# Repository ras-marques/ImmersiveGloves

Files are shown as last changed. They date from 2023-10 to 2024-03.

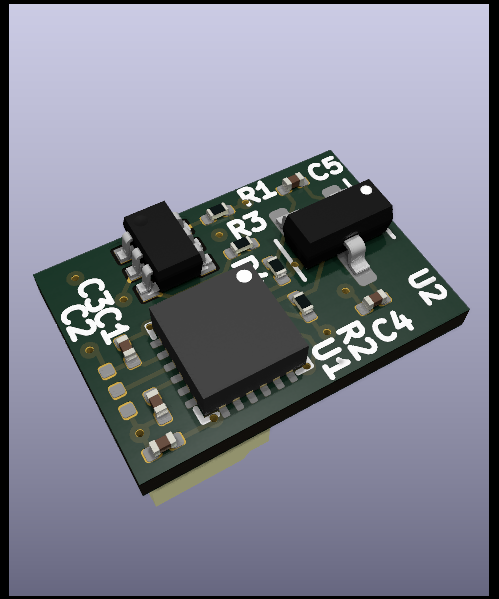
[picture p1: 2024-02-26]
CustomPCBs/InDevelopment/ICM-20948_First_Bone/ICM-20948_First_Bone_top.png

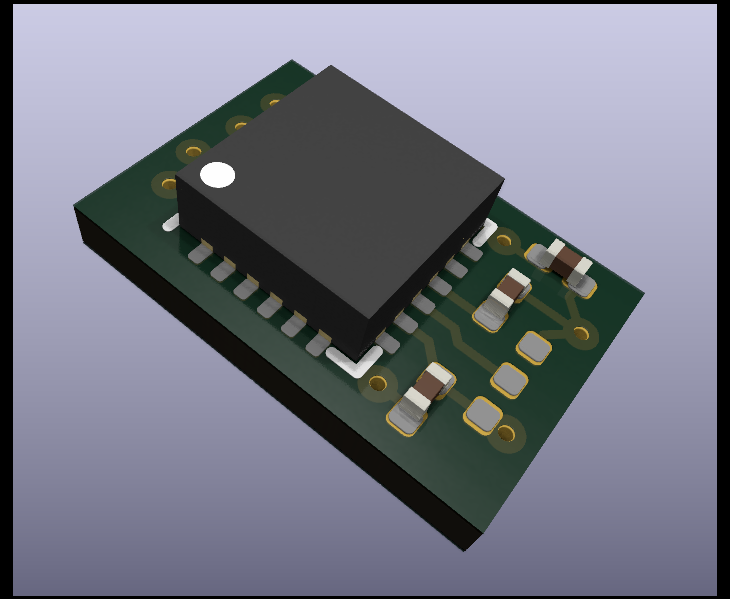
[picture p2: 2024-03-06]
CustomPCBs/InDevelopment/ICM-20948_I2C_1V8_levels/ICM-20948_I2C_1V8_levels_3D_top.png

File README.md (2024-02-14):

# ImmersiveGloves

I want to share how I am making vr gloves using 2 Tundra Trackers, 2 interface boards and 12 inertial sensors.

https://github.com/ras-marques/ImmersiveGloves/assets/6479742/4af1af61-4261-44ce-aa3d-e45de0df7709

Check the full presentation on youtube https://www.youtube.com/watch?v=5OSYiYDkOE8

Hand tracking works with curl and splay on all fingers with 1 IMU on each finger. There is a joystick that is enabled by touching the thumb to the index finger and B, A and System buttons are available by touching the thumb to the middle, ring and pinky fingers respectively.

## Overall repository state

Instructions are incomplete.
The files for the main board and IMU boards are updated.
There is only code for the right glove.
3D printing files need tweaking.

## Necessary equipment and skills

 - Bare PCBs: https://github.com/ras-marques/ImmersiveGloves/tree/main/CustomPCBs/ReadyToTest
 - Components for populating the PCBs: https://github.com/ras-marques/ImmersiveGloves/blob/main/CustomPCBs/cost_analysis.ods
 - Solder paste
 - Hot air gun or hot plate
 - Soldering iron
 - Hot glue gun or super glue
 - 3d printer
 - Pre-crimped JST 1.0mm silicon wire kit: https://www.amazon.es/gp/product/B07PDQKHJ2/ref=ppx_yo_dt_b_asin_title_o00_s00?ie=UTF8&psc=1

The hardest part in this project is making the boards. I am currently not supplying boards, so you will need to order them from somewhere.

The boards are 4 layer and have fine pitch components. Making the PCBs at home is out of the question, but you can order them from JLCPCB, PCBWAY, etc.

I assembled the components on my glove by hand using a stencil to dispense solder paste and used a hot air gun for reflowing. A hot plate is better.

If you don't have a 3d printer, you could order the models from somewhere or ask a friend.

Currently everything is glued to the glove fabric, you could use hot glue or super glue.

The pre-crimped JST wires are necessary to make the assembly process easier, more below.

## Cost analysis

A realistic ballpark for cost is around 250€ per pair of gloves with component and shipping cost and assuming you already have all the tools like a 3d printer, and soldering tools.

You can refer to https://github.com/ras-marques/ImmersiveGloves/blob/main/CustomPCBs/cost_analysis.ods for the complete BOM, but in summary the current cost is described below:
- 4€/pair times 50 = 200€: Cost to make enough boards for exactly 50 pairs of these gloves
- 170€/pair: Cost to source enough components and some spares for a pair of these gloves
- 130€/pair times 50 = 6500€: Cost to source enough compoents for 50 pairs of these gloves

## Tracking method

Why base these gloves around the Tundra Tracker? Using a Tundra Tracker and an expansion board avoids having to deal with batteries, since the Tundra Tracker can power everything. Also, the tracker takes care of transmiting the data from the gloves to the computer wirelessly. Two RP2040's take care of acquiring the data from the 6 inertial sensors, processing it and delivering it to the tracker.

This project is for people that already have a laser tracked VR setup with base stations and ideally for people using Tundra Trackers for full body tracking. That said, if you don't have the Tundra Trackers yet, there are some options:
- 400€: 2 bundles of individual tundra tracker and SW1 dongle (2 USB ports needed) https://unboundxr.eu/tundra-tracker?sqr=tundra + https://unboundxr.eu/tundra-sw1-dongle
- 459€: 3 Tundra Tracker bundle (1 USB port needed) https://unboundxr.eu/tundra-x3-bundle
- 609€: 4 Tundra Tracker bundle (1 USB port needed) https://unboundxr.eu/tundra-x4-bundel

On top of this, if you don't have base stations, those go for 159€ from valve and it is better to have 2.

## End goal for these gloves

- The Tundra Tracker is amazing, it's the smaller tracker available and it even supports sending sensor data to the computer. This is the ultimate tracker for these gloves, but I want to make these more accessible for everyone, so I will want to support more tracking methods, begining with using your available controllers just like LucidVR does. This will probably imply a redesign of the main board to make it possible to power it using an external battery.
- I started this project with the Slime VR BNO085 boards and have since designed a custom BNO085 that is as small as I could make it. I didn't even include a JST connector and wires are soldered directly to it. To make it easier to assemble though, I am considering including the connector in my next IMU boards. I also want to explore using a cheaper IMU chip like the BMI270 with and without a magnetometer.
- My gloves have finger mobility and a low profile as top priorities, so I have no plans for implementing physical buttons unless absolutelly necessary nor force feedback, but vibration haptics are possible if small enough. I do encourage you to do so and share your own version of these gloves!

## Steps to make the gloves:

### 3D Print the mount points for the tracker
- There are 3D printing files available in the 3DPrintingFiles folder of this repo. This is not a one size fits all kind of mount point. I measured the curvature of the back of my hand with a 3D printed matrix of screw inserts, so it fits me perfectly. I will show my process in the future so you can do the same if you want.

### Prepare the Tundra Tracker
- Download the files from this repository.
- Open folder {Steam}\steamapps\common\SteamVR\tools\lighthouse\bin\win32 ({Steam} is probably C:\Program Files (x86)\Steam on your system, but who knows).
- Copy "ImmersiveGlovesLeft.json" and "ImmersiveGlovesRight.json" from this repository into this folder.
- Disconnect every vr device you have from your computer, including the dongles that receive data from the trackers. Using a USB cable, connect just one Tundra Tracker to your computer.
- Write "cmd" on the address bar to open a Command Line inside {Steam}\steamapps\common\SteamVR\tools\lighthouse\bin\win32.
- Write "lighthouse_console.exe" on the Command Line and press return.
- You should see only one device connected, if there are more, make sure to disconnect them, this is **important**. Write "downloadconfig backup.json" to store a backup of the Tundra Tracker config file that is stored inside the tracker.
- Store the config of "ImmersiveGlovesRight.json" to the tracker with "uploadconfig ImmersiveGlovesRight.json" from the command line. This will be the tracker for your right glove.
- Disconnect the tracker and connect another one.
- Store the config of "ImmersiveGlovesLeft.json" to the tracker with "uploadconfig ImmersiveGlovesLeft.json" from the command line. This will be the tracker for your left glove.
- Finally install the ImmersiveGloves driver by copying the folder driverProject/immersive_gloves_controller/build/immersive_gloves_controller on the repository to {Steam}\steamapps\common\SteamVR\drivers\

### Flash the RP2040 board (files not yet available!)
- Download the latest stable version of circuitpython version from here https://circuitpython.org/board/raspberry_pi_pico/
- Connect your expansion board to the Tundra Tracker and then to your PC using the included USB board connected to USB1.
- With the Tracker OFF, press the button on the USB board and while it is pressed, power up the Tundra Tracker, this will let you put the RP2040 in the expansion board in bootloader mode.
- A window should appear on your PC showing the new drive that is emulated by the RP2040. Copy the circuitpython file you downloaded earlier into this folder. The RP2040 will reboot automatically.
- Like before, a new window should appear on your PC showing another drive but now with a different structure. This is where you will put your program that processes the sensor data and sends it to the computer. Just copy the contents of the rp2040Firmware/usb1 folder into the root of this new folder that appeared.
- Repeat the steps above for the second RP2040 mcu by using USB2 and the files in rp2040Firmware/usb2

### Drivers
- We are using the OpenGloves driver so we can easily get inputs working with all apps that support the Index Controllers, which are most of them. So download it from steam: https://store.steampowered.com/app/1574050/OpenGloves/
- Copy the contents of driverProject/immersive_gloves_controller/build/immersive_gloves_controller in this repo to C:\Program Files (x86)\Steam\steamapps\common\SteamVR\drivers or wherever you have your SteamVR app installed.
- Be sure to enable both opengloves and immersive_gloves_controller addon by going to SteamVR settings, Startup/Shutdown tab and clicking Manage SteamVR Add-Ons. These two should be toggled on. Everytime SteamVR shuts down due to an error, it is likely one or both will be toggled off, so check this if something is not working.
- You should calibrate the rotation and position offsets on the OpenGloves configuration panel. I did that manually since I don't have buttons on the glove yet to trigger the callibration interface. Pre-calibrated files may be available in the future with instructions on how to use them.

## Important resources that made this project possible
 
Tundra Labs have a repo with some documentation on how to use their development board https://github.com/tundra-labs/rp2040_examples

CircuitPython allowed me to easily get the inertial sensors working without me having to program everything from scratch, you can learn more about this here https://learn.adafruit.com/adafruit-9-dof-orientation-imu-fusion-breakout-bno085/python-circuitpython

Finally Functional's Open VR Driver Tutorial that was a great introduction on how OpenVR inputs work https://www.youtube.com/watch?v=LzEIOBnbC8k

OpenVR repository has lots of documentation, it takes a while to figure out the parts that are important for this project, but it's worth the effort https://github.com/ValveSoftware/openvr

[danwillm](https://github.com/danwillm) helped me get this thing started by pointing me in the right direction, telling me what technologies to use to speak with the tracker and openvr.

## Contributing workflow

Here’s how I suggest you go about proposing a change to this project:

1. [Fork this project][fork] to your account.
2. [Create a branch][branch] for the change you intend to make.
3. Make your changes to your fork.
4. [Send a pull request][pr] from your fork’s branch to our `main` branch.

Using the web-based interface to make changes is fine too, and will help you by automatically forking the project and prompting to send a pull request too.

[fork]: https://help.github.com/articles/fork-a-repo/
[branch]: https://help.github.com/articles/creating-and-deleting-branches-within-your-repository
[pr]: https://help.github.com/articles/using-pull-requests/

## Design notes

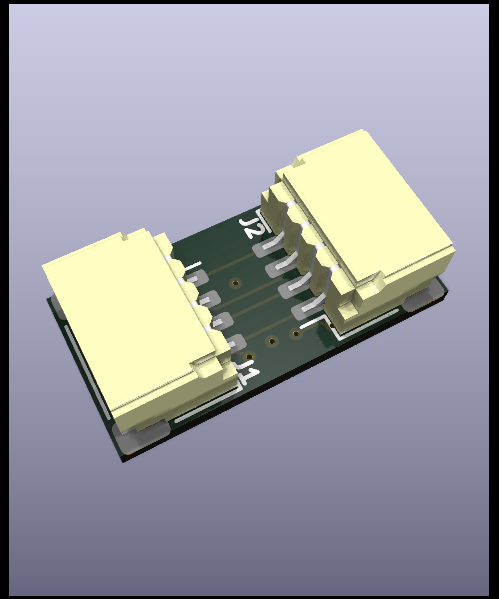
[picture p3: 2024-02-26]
CustomPCBs/InDevelopment/BMI160-and-QMC5883L_Second_Bone/BMI160-and-QMC5883L_Second_Bone_bot.png

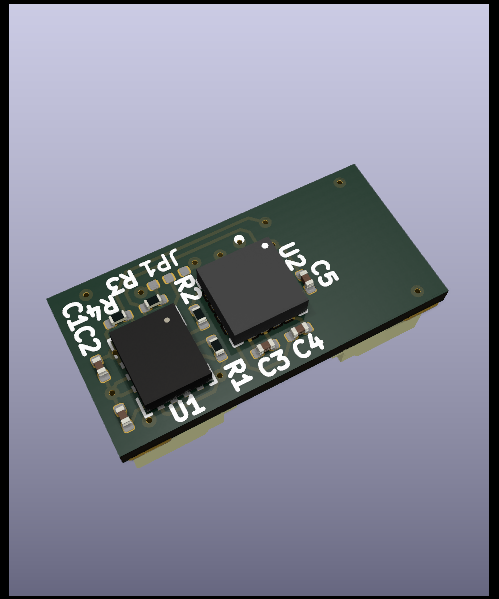
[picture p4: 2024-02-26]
CustomPCBs/InDevelopment/BMI160-and-QMC5883L_Second_Bone/BMI160-and-QMC5883L_Second_Bone_top.png

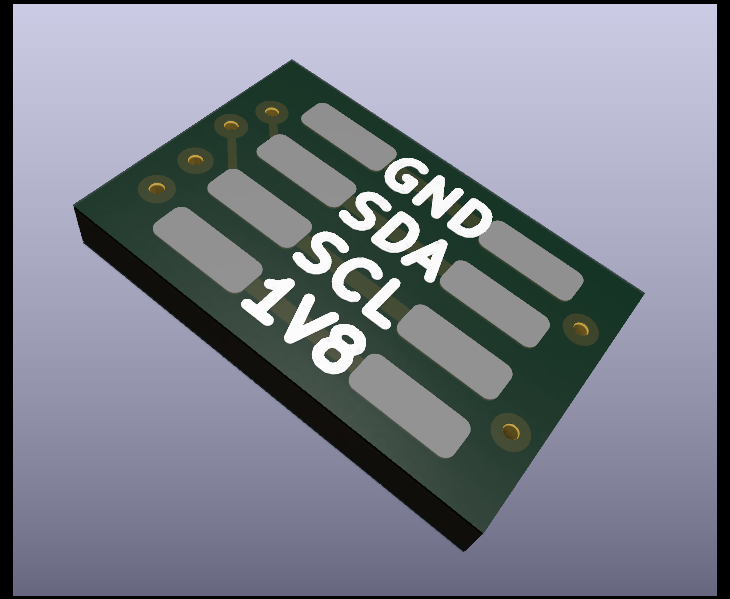
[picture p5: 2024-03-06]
CustomPCBs/InDevelopment/ICM-20948_I2C_1V8_levels/ICM-20948_I2C_1V8_levels_3D_bot.png

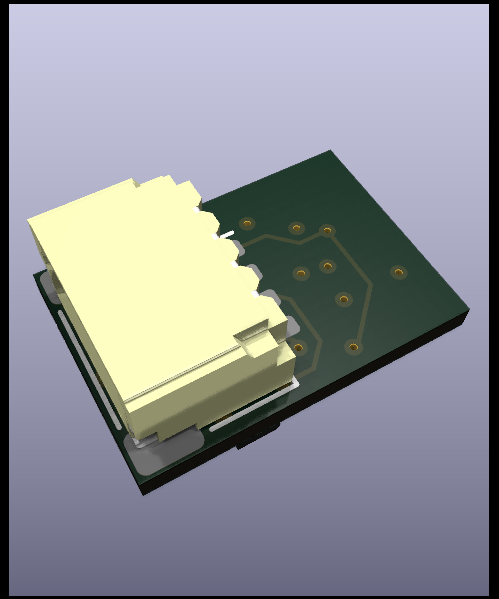
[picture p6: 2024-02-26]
CustomPCBs/InDevelopment/ICM-20948_First_Bone/ICM-20948_First_Bone_bot.png

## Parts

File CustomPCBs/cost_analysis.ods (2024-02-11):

# | Reference | Qty | Value | Footprint | DNP | total/pair | total combined/pair | max unit price | max price/pair | store item | total/50 pairs | min unit price | min price/50 pairs | store item
Expansion Boards |  |  |  |  |  |  |  | minimum qty |  |  |  | enough qty
1 | C1, C7, C10, C17, C23, C28 | 6 | 2.2u | Capacitor_SMD:C_0402_1005Metric |  | 12 | 12 | 0.014 | 0.168 | https://pt.farnell.com/samsung-electro-mechanics/cl05a225mq5nnnc/cap-2-2uf-6-3v-mlcc-0402/dp/3013335 | 600 | 0.007 | 4.2 | https://pt.farnell.com/samsung-electro-mechanics/cl05a225mq5nnnc/cap-2-2uf-6-3v-mlcc-0402/dp/3013335
2 | C2, C3, C4, C5, C6, C8, C9, C13, C14, C18, C20, C22, C24, C25, C26, C27 | 16 | 100n | Capacitor_SMD:C_0402_1005Metric |  | 32 | 62 | 0.004 | 0.248 | https://pt.farnell.com/multicomp/mc0402x104m160ct/cap-0-1-f-16v-20-x5r-0402/dp/2627420 | 3100 | 0.004 | 12.4 | https://pt.farnell.com/multicomp/mc0402x104m160ct/cap-0-1-f-16v-20-x5r-0402/dp/2627420
3 | C11, C12, C19, C21 | 4 | 27p | Capacitor_SMD:C_0402_1005Metric |  | 8 | 8 | 0.008 | 0.064 | https://pt.farnell.com/kemet/c0402c270k5gactu/cap-27pf-50v-10-c0g-np0-0402/dp/2904560 | 400 | 0.008 | 3.2 | https://pt.farnell.com/kemet/c0402c270k5gactu/cap-27pf-50v-10-c0g-np0-0402/dp/2904560
4 | C15, C16 | 2 | 22p | Capacitor_SMD:C_0402_1005Metric |  | 4 | 24 | 0.011 | 0.264 | https://pt.farnell.com/multicomp/mc0402n220j250ct/cap-22pf-25v-5-c0g-np0-0402/dp/2627394 | 1200 | 0.004 | 4.8 | https://pt.farnell.com/multicomp/mc0402n220j250ct/cap-22pf-25v-5-c0g-np0-0402/dp/2627394
5 | FINGER1, FINGER2, FINGER3, FINGER4, FINGER5L1, FINGER5R1, USB1, USB2 | 8 | Conn_01x04 | Connector_JST:JST_SH_SM04B-SRSS-TB_1x04-1MP_P1.00mm_Horizontal |  | 16 | 16 | 0.327 | 5.232 | https://pt.farnell.com/jst-japan-solderless-terminals/sm04b-srss-tb-lf-sn/connector-header-smt-r-a-1mm-4way/dp/1830839 | 800 | 0.226 | 180.8 | https://pt.farnell.com/jst-japan-solderless-terminals/sm04b-srss-tb-lf-sn/connector-header-smt-r-a-1mm-4way/dp/1830839
6 | FingerAux1 | 1 | Conn_01x08 | Connector_JST:JST_SH_SM08B-SRSS-TB_1x08-1MP_P1.00mm_Horizontal |  | 2 | 2 | 0.784 | 1.568 | https://pt.farnell.com/jst-japan-solderless-terminals/sm08b-srss-tb-lf-sn/header-r-a-8way/dp/1679124 | 100 | 0.648 | 64.8 | https://pt.farnell.com/jst-japan-solderless-terminals/sm08b-srss-tb-lf-sn/header-r-a-8way/dp/1679124
7 | J1 | 1 | Conn_01x25 | my_connectors:25PIN FRONT FLIP 0.6mm PITCH AYF332535A |  | 2 | 2 | 1.75 | 3.5 | https://pt.mouser.com/ProductDetail/Panasonic-Industrial-Devices/AYF332535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 | 100 | 1.37 | 137 | https://pt.mouser.com/ProductDetail/Panasonic-Industrial-Devices/AYF332535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
8 | R1, R8 | 2 | 200 | Resistor_SMD:R_0402_1005Metric |  | 4 | 4 | 0.004 | 0.016 | https://pt.farnell.com/en-PT/multicomp/mcwr04x2000ftl/res-200r-1-0-0625w-thick-film/dp/2447132 | 200 | 0.0033 | 0.66 | https://pt.farnell.com/en-PT/multicomp/mcwr04x2000ftl/res-200r-1-0-0625w-thick-film/dp/2447132
9 | R2, R7, R9, R10 | 4 | 1k | Resistor_SMD:R_0402_1005Metric |  | 8 | 8 | 0.005 | 0.04 | https://pt.farnell.com/en-PT/multicomp/mcwr04x1001ftl/res-1k-1-0-0625w-thick-film/dp/2447120 | 400 | 0.002 | 0.8 | https://pt.farnell.com/en-PT/multicomp/mcwr04x1001ftl/res-1k-1-0-0625w-thick-film/dp/2447120
10 | R3, R4 | 2 | 10k | Resistor_SMD:R_0402_1005Metric |  | 4 | 24 | 0.005 | 0.12 | https://pt.farnell.com/en-PT/multicomp/mcmr04x1002ftl/res-10k-1-0-063w-0402-ceramic/dp/2072517 | 1200 | 0.0015 | 1.8 | https://pt.farnell.com/en-PT/multicomp/mcmr04x1002ftl/res-10k-1-0-063w-0402-ceramic/dp/2072517
11 | R5, R6 | 2 | 2k2 | Resistor_SMD:R_0402_1005Metric |  | 4 | 24 | 0.005 | 0.12 | https://pt.farnell.com/multicomp/mcmr04x2201ftl/res-2k2-1-0-0625w-0402-ceramic/dp/2072780 | 1200 | 0.0019 | 2.28 | https://pt.farnell.com/multicomp/mcmr04x2201ftl/res-2k2-1-0-0625w-0402-ceramic/dp/2072780
12 | U1, U5 | 2 | RP2040 | Package_DFN_QFN:QFN-56-1EP_7x7mm_P0.4mm_EP3.2x3.2mm |  | 4 | 4 | 0.755 | 3.02 | https://pt.farnell.com/raspberry-pi/rp2040ct/mcu-32bit-133mhz-qfn-56/dp/3766082?st=rp2040 | 200 | 0.755 | 151 | https://pt.farnell.com/raspberry-pi/rp2040ct/mcu-32bit-133mhz-qfn-56/dp/3766082?st=rp2040
13 | U2, U4 | 2 | W25Q64JVSSIQ | Package_SO:SOP-8_5.28x5.23mm_P1.27mm |  | 4 | 4 | 0.949 | 3.796 | https://pt.mouser.com/ProductDetail/Winbond/W25Q64JVSSIQ?qs=qSfuJ%252Bfl%2Fd4DecxlHDmB8w%3D%3D | 200 | 0.761 | 152.2 | https://pt.mouser.com/ProductDetail/Winbond/W25Q64JVSSIQ?qs=qSfuJ%252Bfl%2Fd4DecxlHDmB8w%3D%3D
14 | U3 | 1 | BNO085 | Package_LGA:LGA-28_5.2x3.8mm_P0.5mm |  | 2 | 12 | 11.76 | 141.12 | https://pt.mouser.com/ProductDetail/CEVA/BNO085?qs=ulEaXIWI0c9BFVeZDQCmmQ%3D%3D | 600 | 8.89 | 5334 | https://pt.mouser.com/ProductDetail/CEVA/BNO085?qs=ulEaXIWI0c9BFVeZDQCmmQ%3D%3D
15 | Y1, Y2 | 2 | 12.000MHz | Crystal:Crystal_SMD_3225-4Pin_3.2x2.5mm |  | 4 | 4 | 0.226 | 0.904 | https://pt.farnell.com/ilsi-america/ilcx13-fb5f18-12-000mhz/crystal-12mhz-18pf-smd-3-2mm-x/dp/3572980 | 200 | 0.189 | 37.8 | https://pt.farnell.com/ilsi-america/ilcx13-fb5f18-12-000mhz/crystal-12mhz-18pf-smd-3-2mm-x/dp/3572980
16 | Y3 | 1 | 32.768kHz | Crystal:Crystal_SMD_2012-2Pin_2.0x1.2mm |  | 2 | 12 | 0.47 | 5.64 | https://pt.farnell.com/en-PT/ecs-inc-international/ecs-327-12-5-12-c/crystal-32-768khz-12-5pf-2mm-x/dp/3649608 | 600 | 0.347 | 208.2 | https://pt.farnell.com/en-PT/ecs-inc-international/ecs-327-12-5-12-c/crystal-32-768khz-12-5pf-2mm-x/dp/3649608
 |  |  |  |  |  |  |  | Total | 165.82 |  |  | Total | 6295.94
IMU Boards |  |  |  |  |  |  |  |  |  |  |  | Total/pair | 125.9188
1 | C1, C2, C6 | 3 | 100n | Capacitor_SMD:C_0402_1005Metric |  | 30 |  |  |  |  | 1500
2 | C4, C5 | 2 | 22p | Capacitor_SMD:C_0402_1005Metric |  | 20 |  |  |  |  | 1000
3 | J1 | 1 | Conn_01x04_Pin | Library:WireToBoard2x2Wide |  | 10 |  |  |  |  | 500
4 | R1, R2 | 2 | 2k2 | Resistor_SMD:R_0402_1005Metric |  | 20 |  |  |  |  | 1000
5 | R3, R4 | 2 | 10k | Resistor_SMD:R_0402_1005Metric |  | 20 |  |  |  |  | 1000
6 | U1 | 1 | BNO085 | Package_LGA:LGA-28_5.2x3.8mm_P0.5mm |  | 10 |  |  |  |  | 500
7 | Y1 | 1 | 32.768kHz | Crystal:Crystal_SMD_2012-2Pin_2.0x1.2mm |  | 10 |  |  |  |  | 500

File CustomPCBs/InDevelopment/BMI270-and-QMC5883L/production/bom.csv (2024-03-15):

Designator | Footprint | Quantity | Value | LCSC Part #
C1 | 0603 | 1 | 4.7u | C5252398
C2 | 0201 | 1 | 220n | C962109
C3, C4, C5 | 0201 | 3 | 100n | C2909627
R1, R2 | 0201 | 2 | 2k2 | C142018
U1 | XDCR_BMI270 | 1 | BMI270 | C2836813
U2 | XDCR_HMC5883L-TR | 1 | QMC5883L | C976032

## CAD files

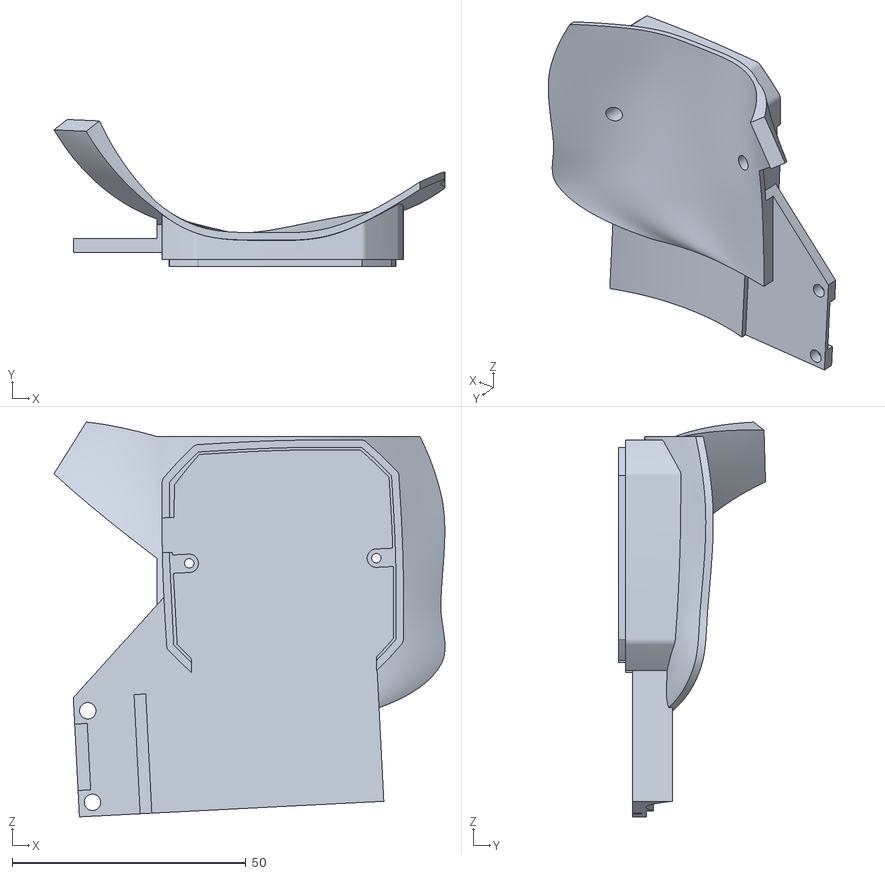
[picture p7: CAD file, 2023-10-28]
3DPrintingFiles/Prototypes/ImmersiveGlovesLeft.stl
83.5 x 31.4 x 84.4

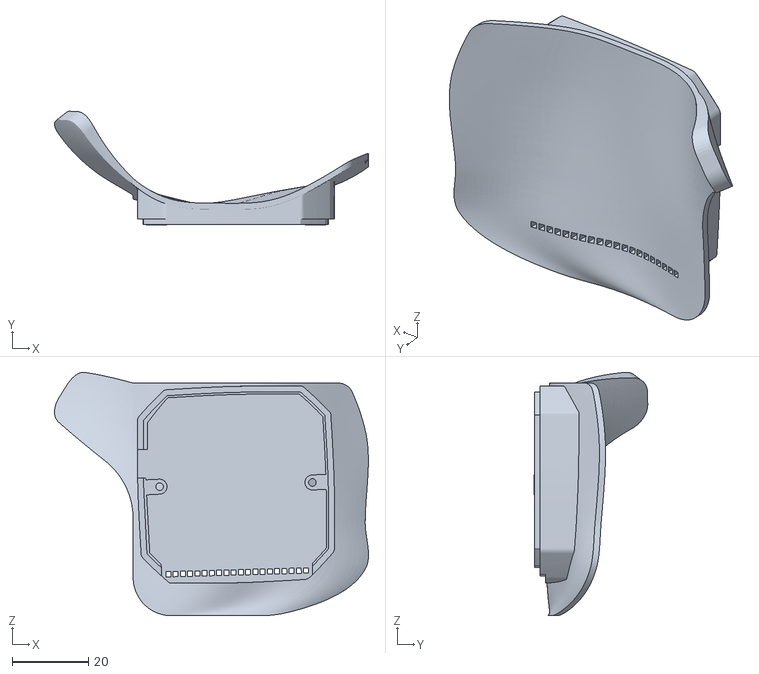
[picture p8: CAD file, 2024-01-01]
3DPrintingFiles/ReadyToTest/BackPlate/BackPlateHolesForWires.stl
82.1 x 29.7 x 63.7

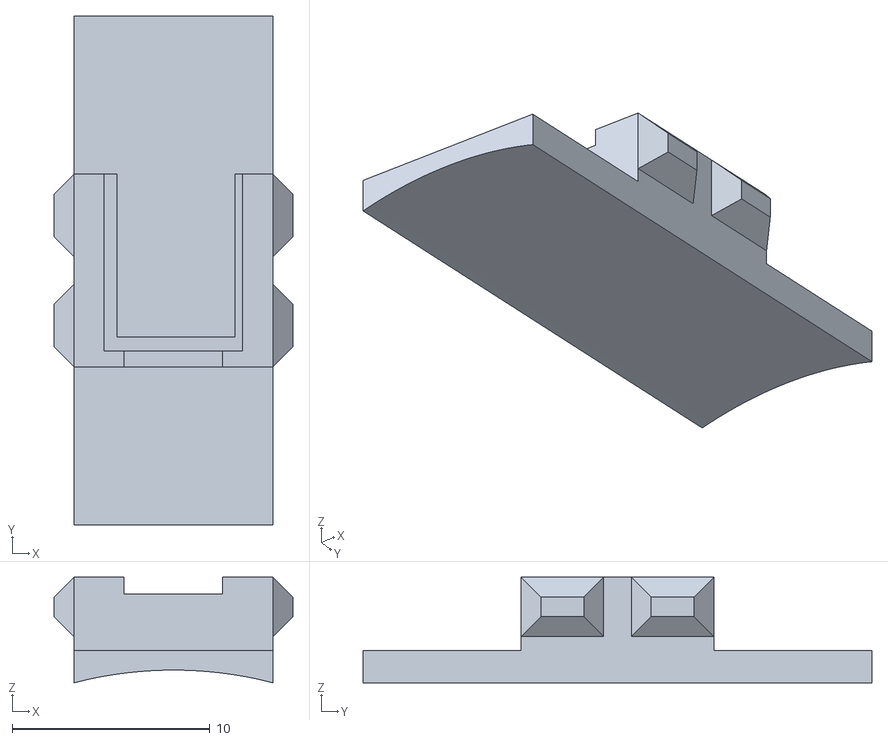
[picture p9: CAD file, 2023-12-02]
3DPrintingFiles/ReadyToTest/IMUHousing/IMUHousingBottomV2.stl
12.1 x 25.8 x 5.34

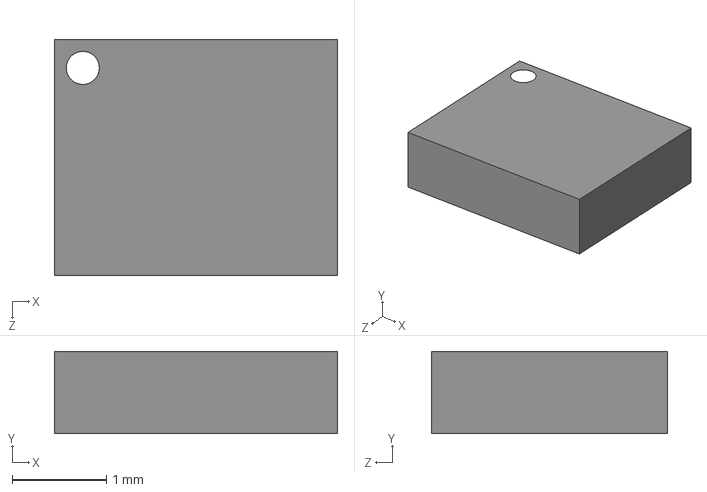
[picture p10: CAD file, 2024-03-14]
CustomPCBs/ComponentLibraries/3dmodels/BMI270.step
3.00 x 0.87 x 2.50 mm

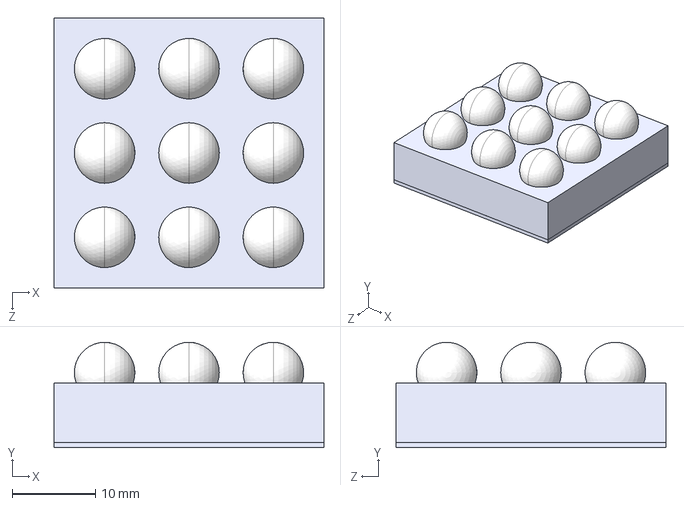
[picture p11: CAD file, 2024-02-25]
CustomPCBs/ComponentLibraries/BMM350.stp
32.5 x 12.7 x 32.5 mm

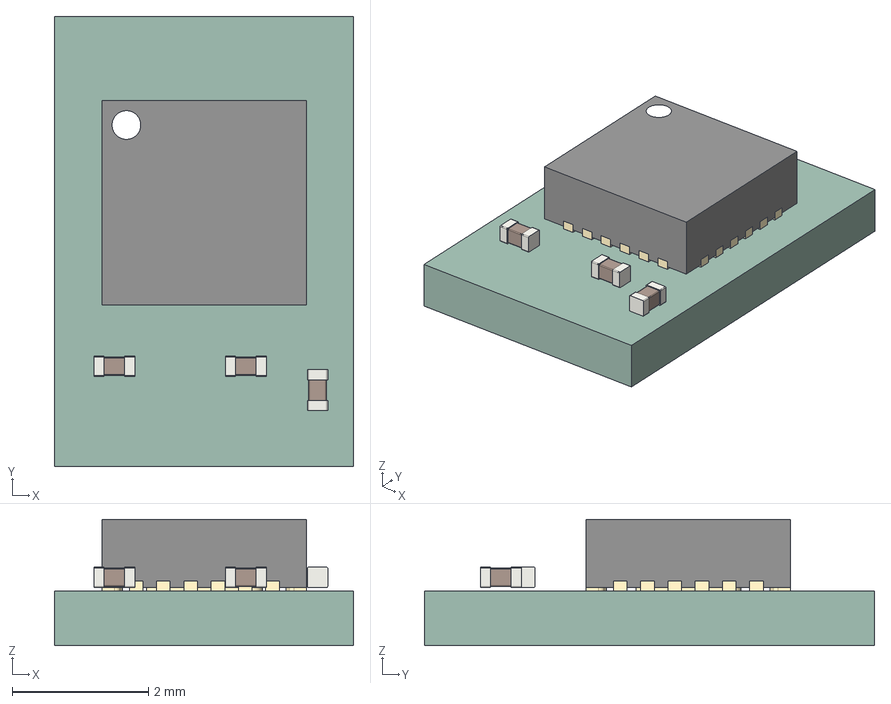
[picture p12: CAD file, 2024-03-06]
CustomPCBs/InDevelopment/ICM-20948_I2C_1V8_levels/ICM-20948_I2C_1V8_levels.step
4.39 x 6.60 x 1.85 mm
ICM-20948_I2C_1V8_levels PCB

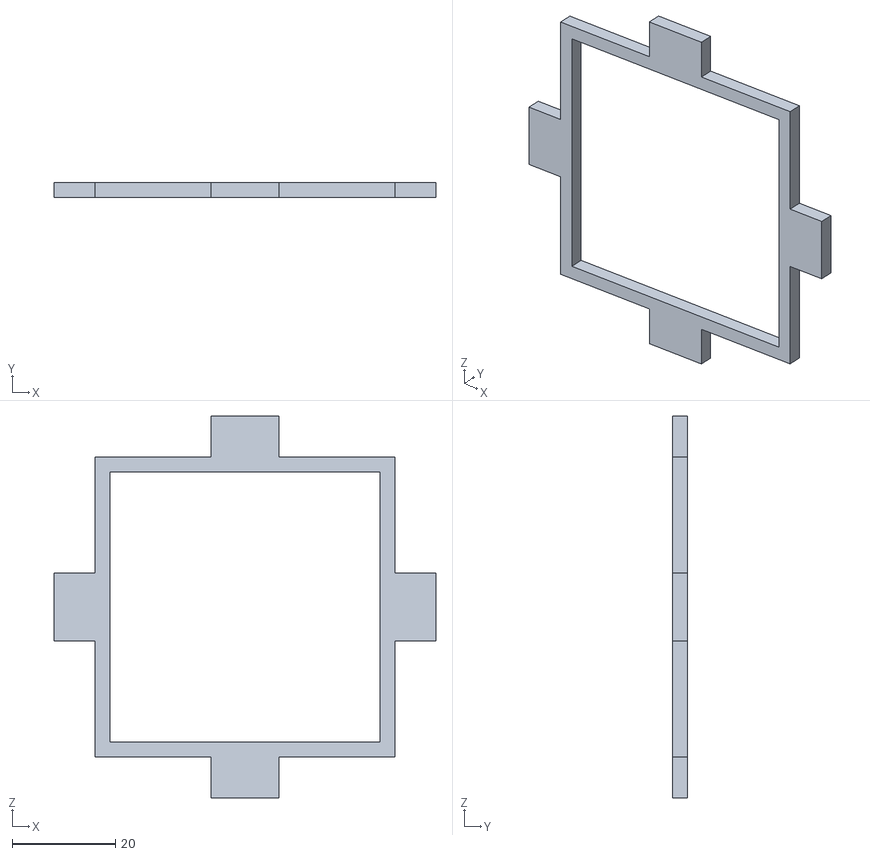
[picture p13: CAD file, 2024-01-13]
CustomPCBs/InDevelopment/tundraIOExpansion/StencilJig/StencilTop.stl
74.1 x 3.00 x 74.1

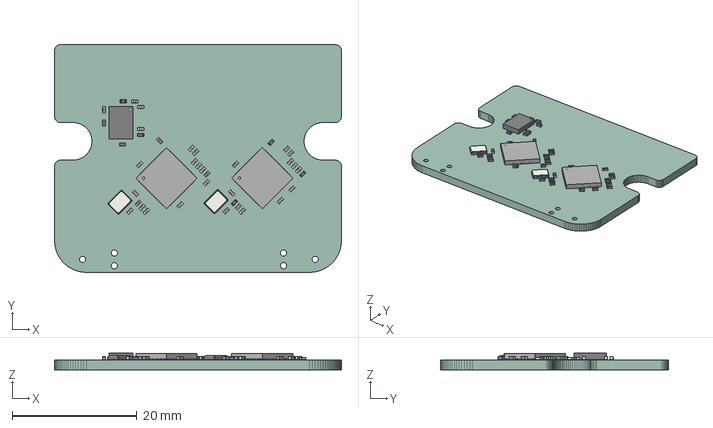
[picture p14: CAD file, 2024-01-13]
CustomPCBs/InDevelopment/tundraIOExpansion/tundraIOExpansion.step
46.0 x 36.5 x 2.67 mm
tundraIOExpansion PCB

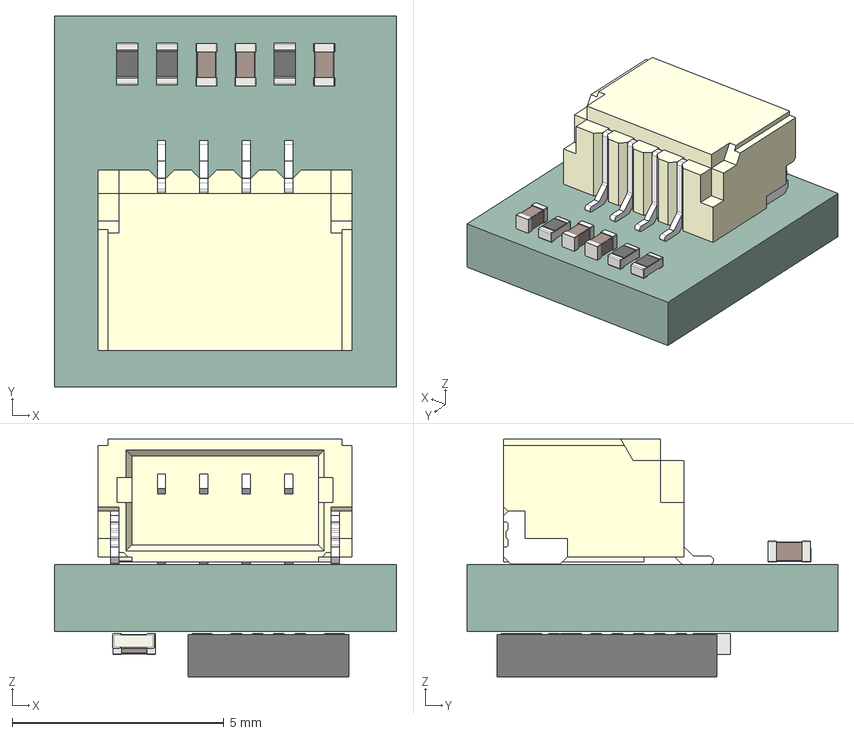
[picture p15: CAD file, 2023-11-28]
CustomPCBs/ReadyToTest/BNO085_0x4B_Board/BNO085_0x4B_Board.step
8.07 x 8.75 x 5.61 mm
BNO085_0x4A_Board PCB

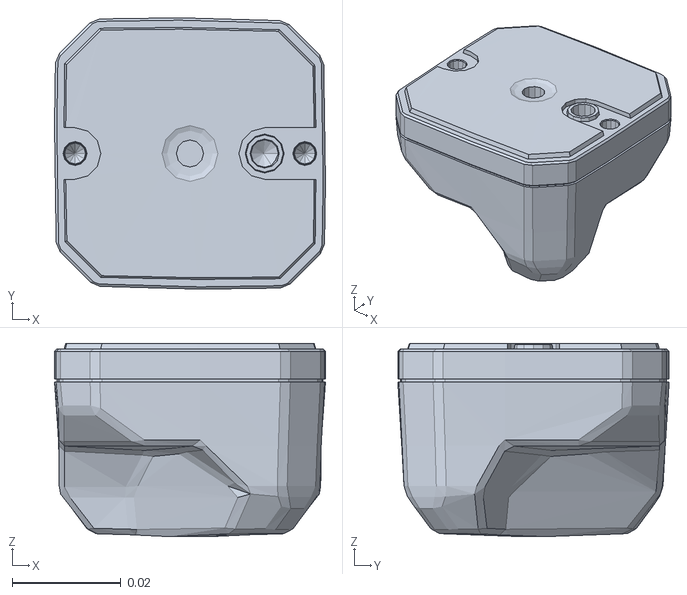
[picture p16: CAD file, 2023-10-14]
driverProject/immersive_gloves_controller/build/immersive_gloves_controller/resources/immersive_gloves_controller/immersive_gloves_controller.obj
0.0499 x 0.05 x 0.0356

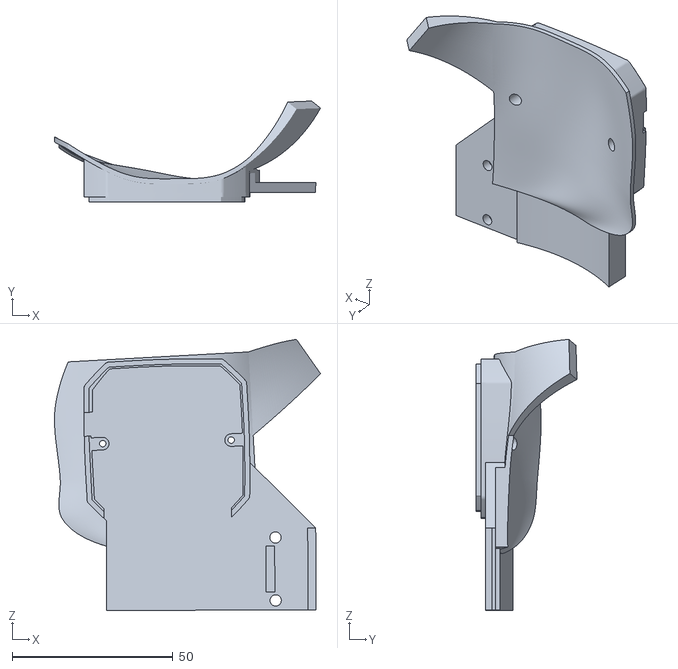
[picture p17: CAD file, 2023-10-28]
3DPrintingFiles/Prototypes/ImmersiveGlovesRight.stl
82.8 x 31.4 x 84.4

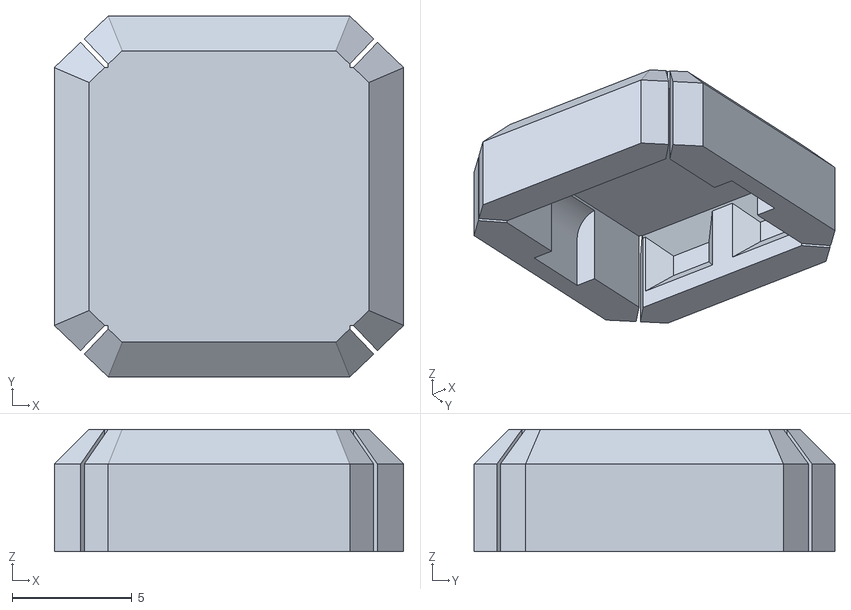
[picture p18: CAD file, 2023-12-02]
3DPrintingFiles/ReadyToTest/BackPlate/IMUHardPointLid.stl
14.6 x 15.0 x 5.11

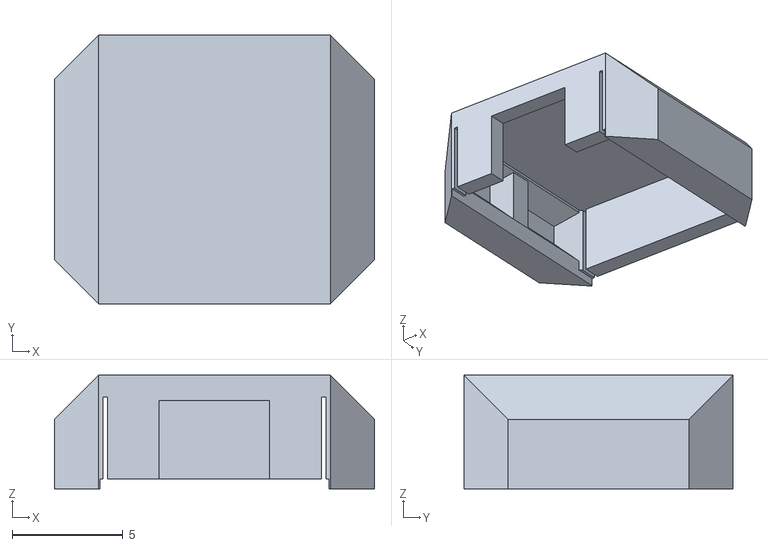
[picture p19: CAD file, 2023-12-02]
3DPrintingFiles/ReadyToTest/IMUHousing/IMUHousingTopV2.stl
14.5 x 12.2 x 5.15

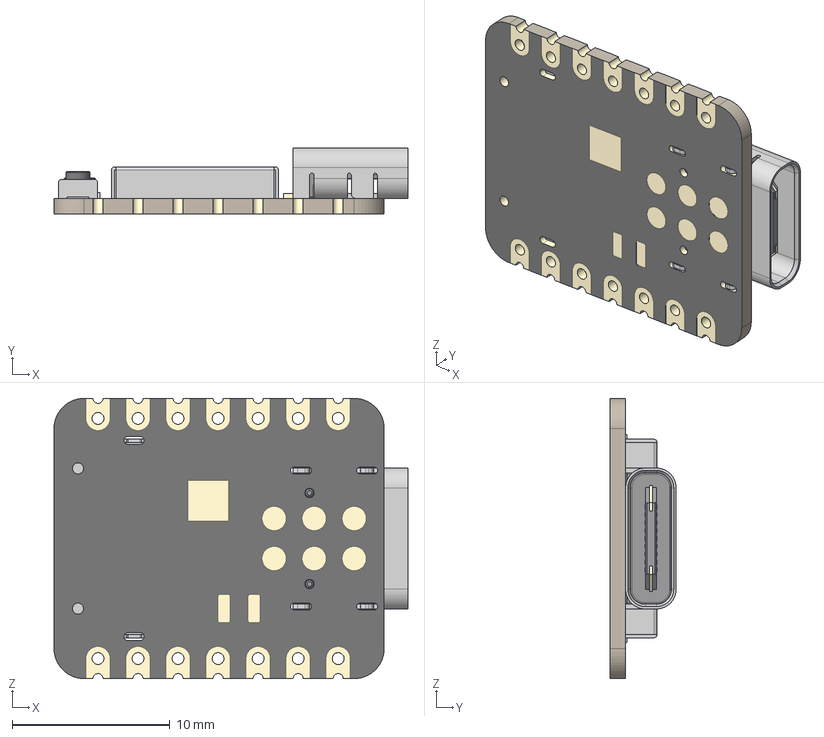
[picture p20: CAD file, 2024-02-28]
CustomPCBs/ComponentLibraries/3dmodels/Seeed Studio XIAO-ESP32-C3.step
22.5 x 4.21 x 17.8 mm
BOSS-EXTRUDE14_8_
BOSS-EXTRUDE7_4_
BOSS-EXTRUDE7_3_
BOSS-EXTRUDE14_4_
BOSS-EXTRUDE14_2_
BOSS-EXTRUDE14_11_
BOSS-EXTRUDE7_7_
BOSS-EXTRUDE14_9_
BOSS-EXTRUDE14_3_
BOSS-EXTRUDE14_7_
MIRROR2
BOSS-EXTRUDE14_5_
BOSS-EXTRUDE14_12_
BOSS-EXTRUDE7_8_
BOSS-EXTRUDE7_1_
BOSS-EXTRUDE14_10_
BOSS-EXTRUDE7_9_
BOSS-EXTRUDE14_6_
BOSS-EXTRUDE14_1_
BOSS-EXTRUDE7_6_
BOSS-EXTRUDE7_2_
CUT-EXTRUDE5
BOSS-EXTRUDE7_5_
U.FL Connector v1
Button (1) x 2
Shield

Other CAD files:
CustomPCBs/ReadyToTest/BNO085_0x4A_Board/StensilJig/StensilJig.FCStd
CustomPCBs/InDevelopment/tundraIOExpansion/StencilJig/StencilBottom.stl
3DPrintingFiles/ReadyToTest/BackPlate/BackPlate.stl
CustomPCBs/ComponentLibraries/3dmodels/6-TSOP.STEP
3DPrintingFiles/ReadyToTest/BackPlate/IMUHardPoint.stl
3DPrintingFiles/ReadyToTest/IMUHousing/IMUHousing.f3d
3DPrintingFiles/ReadyToTest/IMUHousing/IMUHousingBottom.stl
3DPrintingFiles/ReadyToTest/IMUHousing/IMUHousingTop.stl
CustomPCBs/ComponentLibraries/3dmodels/BSS138BKS,115.stp
CustomPCBs/ComponentLibraries/3dmodels/BSS138W-7-F.step
CustomPCBs/ComponentLibraries/3dmodels/HMC5883L-TR.step
CustomPCBs/ComponentLibraries/3dmodels/ICM-20948.step
CustomPCBs/ComponentLibraries/3dmodels/LGA14-L_2P59X3P1X0P5_STM.step
CustomPCBs/ComponentLibraries/3dmodels/SM04B-SRSS-TB.STEP
CustomPCBs/ComponentLibraries/3dmodels/User Library-SOT23-3.step
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

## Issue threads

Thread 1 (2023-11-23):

Add code support for cheaper IMU solutions

ras-marques, 2023-11-23:
We are currently using BNO boards that cost around 15€ each and needing 6 per glove.

There is an existing board we can use to develop the code for the project:
https://oshwlab.com/neosquared2002/MultIMU-Module-for-SlimeVR

I didn't find an off the shelf board that includes a BMI270 and magnetometer, but please share if you know where to get them so development is faster.

ras-marques, 2024-03-07:
https://oshwlab.com/neosquared2002/MultIMU-Module-for-SlimeVR was deleted in the meantime.

SlimeVR already has some code for the next IMU I want to use, the ICM-20948, will focus on porting that next.

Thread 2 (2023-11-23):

Design cheaper IMU board

ras-marques, 2023-11-23:
While not knowing exactly what IMUs to use, the BMI270 together with a magnetometer is a good option. The goal is for the board to fit the fingernail. 4 Layer boards and components on both sides are a must for this to work.

DregonMMM, 2023-11-30:
Both the BMI270 and BMI160 are good options. They are also not too big and use the same pinout so for a custom PCB with a magnetometer you only need a single board design because both chips can be used. If budget is a problem and you don't mind having to recalibrate them more often then you don't need the magnetometer.

ras-marques, 2024-03-07:
ICM-20948 based board has been designed, will close after confirming it is working.

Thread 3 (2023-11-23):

Design hardpoints where to place the IMU boards

ras-marques, 2023-11-23:
The IMU boards need to be fixed to the glove somehow. On the prototype they were hot glued to a 3D printed hardpoint that was also hot glued to the glove.

A better option would be to sew or/and super glue the hardpoint to the glove and clamp the IMU board to it somehow.

We should support people using regular FDM printers but also people with resin printers of greater resolution, hence allowing for smaller hardpoints.

ras-marques, 2023-12-05:
Solved, check [here](https://github.com/ras-marques/ImmersiveGloves/tree/main/3DPrintingFiles)

Closed 2023-12-05.

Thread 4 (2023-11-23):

Find a robust and easy way to route cables from the back of the hand to the finger tips

ras-marques, 2023-11-23:
Our finger sensors are currently on the tip of the fingers. This poses a challenge in routing power and communication from our RP2040 microcontrollers to the IMU boards.

The prototype has hot glue "clips" keeping the cables from going super wild, but a better solution should be used, such as embedding the wires onto the glove fibers, almost like sewing but with copper cables.

ras-marques, 2023-12-05:
The IMU boards were moved to the second finger bone counting from the tip and a hardpoint was designed and prototyped, available [here](https://github.com/ras-marques/ImmersiveGloves/tree/main/3DPrintingFiles). The copper wires are threaded through the glove fabric up to the backplate where the acquisition board is located. This is not an easy task, new wire types should be used, maybe enameled wire is a good option, but special care should be taken during assembly so that the wires don't break over time. More prototyping and testing is needed.

ras-marques, 2024-03-07:
Now using silicone wire, this can be closed.

Closed 2024-03-07.

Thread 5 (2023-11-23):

Design joystick and button interface

ras-marques, 2023-11-23:
My current idea is to coat some parts of the glove with a conductive paste like some sports gloves use to add touchscreen support, and tracking what fingers are in contact with what parts of the glove. Then depending on the motion after contact of the thumb with a part of the glove for example, a kind of input is sent to the computer.

ras-marques, 2023-12-05:
This is now being solved by contacts with a wire mesh on the glove for joystick and buttons, with the joystick being emulated by the attitude of the thumb when it touches a specific area of the glove.

Closed 2023-12-05.

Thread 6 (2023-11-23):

Add more I2C support to the RP2040

ras-marques, 2023-11-23:
We currently need 2 RP2040 to take care of 6 I2C BNO085 boards, since the RP2040 only has 2 I2C interfaces and the BNO085 can only have 2 different addresses, leaving us with each RP2040 being able to support up to 4 IMU boards.

This could be improved in many ways, either by designing the BNO085 boards to use UART or SPI instead of I2C, but I currently don't have that available. I have already tried implementing bitbanged I2C and the data rate plummets from 100Hz to 8Hz, becoming noticeably choppy.

The RP2040 has a super power though, it's PIO machines, that allow us to program mostly any interface in any pin. I haven't tried I2C with PIO, but will be happy if someone manages to get a BNO085 speaking using a PIO emulated I2C device. This would allow for mode space in the main board and more space = more features.

ras-marques, 2024-03-07:
Must try multiplexing I2C on the RP2040 itself, should be possible. What I want to do is reconfigure the same peripheral on other pins between acquisitions. Overhead is probably minimal, but must check.

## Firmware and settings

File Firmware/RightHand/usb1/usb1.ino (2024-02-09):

// #include "tundra_mapped_input.h"
#include "BNO085.h"
#include "Finger.h"
#include "Quaternion.h"
#include <cmath>

#include <hardware/pio.h>

// Our assembled program:
#include "spi_slave.pio.h"

// Any button interaction in the glove is done by touching the thumb to one of the fingers.
// This makes accidental button presses very frequent. To avoid this, a double click on the A button (ring finger) must be executed.
// This action will toggle inputs on and off, while never disabling hand tracking.
bool disableInputs = true;

// Create TMI object to communicate with Tundra Tracker
// TMI tundra_tracker;
// void csn_irq( uint gpio, uint32_t event_mask );  // Chip select IRQ must be top level so let's make one and connect it later in setup

BNO085 bnoIndex;
BNO085 bnoMiddle;
BNO085 bnoRing;
BNO085 bnoPinky;

Finger fingerIndex;
Finger fingerMiddle;
Finger fingerRing;
Finger fingerPinky;

Quaternion handQuaternion;
Quaternion relativeQuaternion;

Quaternion indexQuaternion;
Quaternion middleQuaternion;
Quaternion ringQuaternion;
Quaternion pinkyQuaternion;

float getCurl(Quaternion q){
  return atan2(2 * (q.x * q.w - q.y * q.z), 1 - 2 * (q.x * q.x + q.y * q.y));
}

float getSplay(Quaternion q){
  return atan2(2 * (q.x * q.y + q.z * q.w), 1 - 2 * (q.y * q.y + q.z * q.z));
}

float getRoll(Quaternion q){
  return atan2(2 * (q.y * q.z + q.w * q.x), 1 - 2 * (q.x * q.x + q.y * q.y));
}

// this will be sent by serial to the main MCU - 14 bytes are enough for 112 bits, this struct has 108
typedef struct __attribute__( ( packed, aligned( 1 ) ) )
{
  uint8_t       pinky           : 1;  //0
  uint8_t       ring            : 1;  //1
  uint8_t       middle          : 1;  //2
  uint8_t       index           : 1;  //3
  uint16_t      thumbstick_x    : 10; //4
  uint16_t      thumbstick_y    : 10; //14
  uint16_t      thumbCurl       : 10; //24
  uint16_t      thumbSplay      : 10; //34
  int16_t       refQuaternion_w : 16; //44
  int16_t       refQuaternion_x : 16; //60
  int16_t       refQuaternion_y : 16; //76
  int16_t       refQuaternion_z : 16; //92
} serial_data_t;

union serialDataUnion {
  uint8_t chars_rxed_array[14];
  serial_data_t rxed_data;
} serial_data;

void printSerialData(){
  Serial.print(serial_data.rxed_data.pinky);
  Serial.print("\t");
  Serial.print(serial_data.rxed_data.ring);
  Serial.print("\t");
  Serial.print(serial_data.rxed_data.middle);
  Serial.print("\t");
  Serial.print(serial_data.rxed_data.index);
  Serial.print("\t");
  Serial.print(serial_data.rxed_data.thumbstick_x);
  Serial.print("\t");
  Serial.print(serial_data.rxed_data.thumbstick_y);
  Serial.print("\t");
  Serial.print(serial_data.rxed_data.thumbCurl);
  Serial.print("\t");
  Serial.print(serial_data.rxed_data.thumbSplay);
  Serial.print("\t");
  Serial.print(serial_data.rxed_data.refQuaternion_w);
  Serial.print("\t");
  Serial.print(serial_data.rxed_data.refQuaternion_x);
  Serial.print("\t");
  Serial.print(serial_data.rxed_data.refQuaternion_y);
  Serial.print("\t");
  Serial.println(serial_data.rxed_data.refQuaternion_z);
}

// Make a top level struct that packs the button data along with the rest of the controller analog values
typedef struct __attribute__( ( packed, aligned( 1 ) ) )
{
  uint16_t      thumb_curl        : 10;  //0
  uint16_t      index_curl        : 10;  //10
  uint16_t      middle_curl       : 10;  //20
  uint16_t      ring_curl         : 10;  //30
  uint16_t      pinky_curl        : 10;  //40
  uint16_t      thumb_splay       : 10;  //50
  uint16_t      index_splay       : 10;  //60
  uint16_t      middle_splay      : 10;  //70
  uint16_t      ring_splay        : 10;  //80
  uint16_t      pinky_splay       : 10;  //90
  uint16_t      trigger           : 10;  //100
  uint16_t      thumbstick_x      : 10;  //110
  uint16_t      thumbstick_y      : 10;  //120
  uint8_t       thumbstick_click  : 1;   //130
  uint8_t       triggerbtn        : 1;   //131
  uint8_t       a                 : 1;   //132
  uint8_t       b                 : 1;   //133
  uint8_t       system            : 1;   //134
} controller_data_t;
controller_data_t controller_data;
// 5 32-bit integers can represent  160 bits. This struct has 135.

void printControllerData(){
  Serial.print(controller_data.thumb_curl);
  Serial.print("\t");
  Serial.print(controller_data.index_curl);
  Serial.print("\t");
  Serial.print(controller_data.middle_curl);
  Serial.print("\t");
  Serial.print(controller_data.ring_curl);
  Serial.print("\t");
  Serial.print(controller_data.pinky_curl);
  Serial.print("\t");
  Serial.print(controller_data.thumb_splay);
  Serial.print("\t");
  Serial.print(controller_data.index_splay);
  Serial.print("\t");
  Serial.print(controller_data.middle_splay);
  Serial.print("\t");
  Serial.print(controller_data.ring_splay);
  Serial.print("\t");
  Serial.print(controller_data.pinky_splay);
  Serial.print("\t");
  Serial.print(controller_data.thumbstick_x);
  Serial.print("\t");
  Serial.print(controller_data.thumbstick_y);
  Serial.print("\t");
  Serial.print(controller_data.thumbstick_click);
  Serial.print("\t");
  Serial.print(controller_data.a);
  Serial.print("\t");
  Serial.print(controller_data.b);
  Serial.print("\t");
  Serial.print(controller_data.system);
  Serial.print("\t");
  Serial.print(controller_data.trigger);
  Serial.print("\t");
  Serial.println(controller_data.triggerbtn);
}

uint8_t received_characters[32] = {};

int chars_rxed = 0;
int uart_successes = 0;
int last_received_char = 0;
long microsLastReceived = 0;
bool hasSerialData = false;
// RX interrupt handler
void on_uart_rx() {
  while (uart_is_readable(uart1)) {
    if(micros() - microsLastReceived > 5000){
      chars_rxed = 0;
    }
    received_characters[chars_rxed & 0x1F] = uart_getc(uart1);
    microsLastReceived = micros();
    chars_rxed++;
  }
  if(chars_rxed == 18){
    hasSerialData = true;
    chars_rxed = 0;
  }
}

int debugTransitions = 0;
bool checkDoubleClick(uint64_t button_history){
  if(button_history & 0x1){
    debugTransitions = -1;
    return false; // button still pressed, can't be a double click
  } else{
    // check how many transitions from 0 to 1 and 1 to 0 happened. On a double click, there should be exactly 4
    bool lastState = false;
    int numberOfTransitions = 0;
    for(int i = 0; i < 63; i++){
      bool currentState = button_history & (((uint64_t)1) << i);
      if(lastState != currentState) numberOfTransitions++;
      lastState = currentState;
    }
    debugTransitions = numberOfTransitions;
    if(numberOfTransitions == 4) return true; // double click detected
  }

  return false; // catch all default returning false - no double click detected
}

int interpretErrorType = 0;
int interpretSum = 0;
// comms happen at around 100Hz between USB2 and USB1 and we want to look at the last 500ms or so for double clicks, so we store the last 64 entries of each button in a 64bit int for the last 640ms.
uint64_t thumbstick_btn = 0;
uint64_t a_btn = 0;
uint64_t b_btn = 0;
uint64_t system_btn = 0;
void interpret_serial_data(){
  if((received_characters[0] != 0x55) || (received_characters[1] != 0x55)){
    interpretErrorType = 1;
  	return;
  }
  uint16_t sum = 0;

  for(int i = 0; i < 16; i++){
    sum += received_characters[i];
  }

  interpretSum = sum;

  if(sum != ((received_characters[17] << 8) + received_characters[16])){
    interpretErrorType = 2;
  	return;
  }

  // now that it's confirmed data was received ok, fill serial_data union with the actual data that was received
  for(int i = 0; i < 14; i++){
    serial_data.chars_rxed_array[i] = received_characters[i + 2];
  }

  // finally parse the union serial_data into controller_data that will be sent to the tracker
  controller_data.thumb_curl = serial_data.rxed_data.thumbCurl;
  controller_data.thumb_splay = serial_data.rxed_data.thumbSplay;

  // left shift all FIFOs
  thumbstick_btn = thumbstick_btn << 1;
  a_btn = a_btn << 1;
  b_btn = b_btn << 1;
  system_btn = system_btn << 1;

  thumbstick_btn |= serial_data.rxed_data.index;
  b_btn |= serial_data.rxed_data.middle;
  a_btn |= serial_data.rxed_data.ring;
  system_btn |= serial_data.rxed_data.pinky;

  if(checkDoubleClick(a_btn)) {
    disableInputs = !disableInputs;
    a_btn = 0; // we must reset a_btn here to 0, otherwise there will be multiple double clicks detected until the FIFO is emptied naturally in ~640ms
  }

  if(!disableInputs){
    controller_data.thumbstick_x = serial_data.rxed_data.thumbstick_x;
    controller_data.thumbstick_y = serial_data.rxed_data.thumbstick_y;
    
    controller_data.thumbstick_click = serial_data.rxed_data.index;
    controller_data.b = serial_data.rxed_data.middle;
    controller_data.a = serial_data.rxed_data.ring;
    controller_data.system = serial_data.rxed_data.pinky;

    int tempVariable = controller_data.index_curl * 2;
    if(tempVariable > 1023) controller_data.trigger = 1023;
    else controller_data.trigger = tempVariable;
    if(controller_data.trigger > 850) controller_data.triggerbtn = true;
    else controller_data.triggerbtn = false;
  } else {
    controller_data.thumbstick_x = 512;
    controller_data.thumbstick_y = 512;
    controller_data.thumbstick_click = false;
    controller_data.a = false;
    controller_data.b = false;
    controller_data.system = false;
    controller_data.trigger = 0;
    controller_data.triggerbtn = false;
  }

  relativeQuaternion.w = serial_data.rxed_data.refQuaternion_w / 32767.;
  relativeQuaternion.x = serial_data.rxed_data.refQuaternion_x / 32767.;
  relativeQuaternion.y = serial_data.rxed_data.refQuaternion_y / 32767.;
  relativeQuaternion.z = serial_data.rxed_data.refQuaternion_z / 32767.;
}

void initialize_serial(){
  Serial.begin(115200);
  // while(!Serial) // can't use this here, otherwise it only works with usb connected!

  delay(2000);
  Serial.println("ImmersiveGloves starting...");
  delay(1000); // wait 1 seconds, USB2 waits 3 seconds, so that we are sure USB2 has UART aligned for now - probably will make this better later
}

PIO pio = pio0;
uint offset;
uint sm;

void initialize_pio_for_spi_comms_with_tracker(){
  offset = pio_add_program(pio, &spi_slave_program);
  sm = pio_claim_unused_sm(pio, true);
  int mosi = 12;
  int cs = 13;
  int sclk = 14;
  int miso = 15;
  spi_slave_init(pio, sm, offset, mosi, cs, sclk, miso);
}

void initialize_imus(){
  // Initialize I2C
  _i2c_init(i2c0, 400000);             // Init I2C0 peripheral at 400kHz
  gpio_set_function(0, GPIO_FUNC_I2C); // set pin 0 as an I2C pin (SDA in this case)
  gpio_set_function(1, GPIO_FUNC_I2C); // set pin 1 as an I2C pin (SCL in this case)
  gpio_pull_up(0);                     // use internal pull up on pin 0
  gpio_pull_up(1);                     // use internal pull up on pin 1
  Serial.println("I2C0 configured");

  _i2c_init(i2c1, 400000);             // Init I2C1 peripheral at 400kHz
  gpio_set_function(2, GPIO_FUNC_I2C); // set pin 2 as an I2C pin (SDA in this case)
  gpio_set_function(3, GPIO_FUNC_I2C); // set pin 3 as an I2C pin (SCL in this case)
  gpio_pull_up(2);                     // use internal pull up on pin 2
  gpio_pull_up(3);                     // use internal pull up on pin 3
  Serial.println("I2C1 configured");

  delay(1000);                         // Give the IMUs time to boot up

  Serial.println("Initializing Index IMU");
  bnoIndex.begin(i2c1, 0x4A);
  Serial.println("Initializing Middle IMU");
  bnoMiddle.begin(i2c1, 0x4B);
  Serial.println("Initializing Ring IMU");
  bnoRing.begin(i2c0, 0x4A);
  Serial.println("Initializing Pinky IMU");
  bnoPinky.begin(i2c0, 0x4B);
}

void initialize_fingers(){
  // sets initial calibration of splay angles for each finger during initialization
  // begin(float degreesMin, float degreesMid, float degreesMax)
  fingerIndex.begin(-13.06, 16.94, 46.94);
  fingerMiddle.begin(-34.77, -4.77, 25.23);
  fingerRing.begin(-43.70, -13.70, 16.30);
  fingerPinky.begin(-61.91, -31.91, -1.91);
}

void initialize_uart(){
  // Set up our UART with the required speed.
  uart_init(uart1, 115200);
  // Set the TX and RX pins by using the function select on the GPIO
  // Set datasheet for more information on function select
  gpio_set_function(4, GPIO_FUNC_UART);
  gpio_set_function(5, GPIO_FUNC_UART);

  // Turn off FIFO's - we want to do this character by character
  uart_set_fifo_enabled(uart1, false);

  // Set up and enable the interrupt handlers
  irq_set_exclusive_handler(UART1_IRQ, on_uart_rx);
  irq_set_enabled(UART1_IRQ, true);

  // Now enable the UART to send interrupts - RX only
  uart_set_irq_enables(uart1, true, false);

  // Reference functions below:
  // uart_putc_raw(uart1, 'A');           // Send out a character without any conversions
  // uart_putc(uart1, 'B');               // Send out a character but do CR/LF conversions
  // uart_puts(uart1, " Hello, UART!\n"); // Send out a string, with CR/LF conversions
}
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
void loop() {
  // Take measurements synchronously with thumb and reference data received through serial
  if(hasSerialData){
    interpret_serial_data();
    hasSerialData = false;

    bnoIndex.getReadings();
    bnoMiddle.getReadings();
    bnoRing.getReadings();
    bnoPinky.getReadings();

    if(bnoIndex.hasNewQuaternion){
      // Serial.println("index");
      Quaternion sensorQuaternion;
      float radAccuracy;
      uint8_t accuracy;
      bnoIndex.getQuat(sensorQuaternion.x, sensorQuaternion.y, sensorQuaternion.z, sensorQuaternion.w, radAccuracy, accuracy);  // get the index IMU quaternion

      fingerIndex.computeAxesValues(relativeQuaternion, sensorQuaternion);  // compute curl and splay axis from reference quaternion and finger quaternion

      controller_data.index_curl = fingerIndex.curlAxis;
      controller_data.index_splay = fingerIndex.splayAxis;
      // controller_data.index_splay = (fingerIndex.splayAxis * 0.8) + 200;
    }

    if(bnoMiddle.hasNewQuaternion){
      // Serial.println("middle");
      Quaternion sensorQuaternion;
      float radAccuracy;
      uint8_t accuracy;
      bnoMiddle.getQuat(sensorQuaternion.x, sensorQuaternion.y, sensorQuaternion.z, sensorQuaternion.w, radAccuracy, accuracy);  // get the middle IMU quaternion
      
      fingerMiddle.computeAxesValues(relativeQuaternion, sensorQuaternion);  // compute curl and splay axis from reference quaternion and finger quaternion

      controller_data.middle_curl = fingerMiddle.curlAxis;
      controller_data.middle_splay = fingerMiddle.splayAxis;
      // controller_data.middle_splay = (fingerMiddle.splayAxis * 0.6) + 400;
    }

    if(bnoRing.hasNewQuaternion){
      // Serial.println("ring");
      Quaternion sensorQuaternion;
      float radAccuracy;
      uint8_t accuracy;
      bnoRing.getQuat(sensorQuaternion.x, sensorQuaternion.y, sensorQuaternion.z, sensorQuaternion.w, radAccuracy, accuracy);                    // get the ring IMU quaternion
      
      fingerRing.computeAxesValues(relativeQuaternion, sensorQuaternion);  // compute curl and splay axis from reference quaternion and finger quaternion

      controller_data.ring_curl = fingerRing.curlAxis;
      controller_data.ring_splay = fingerRing.splayAxis;
      // controller_data.ring_splay = (fingerRing.splayAxis * 0.85) + 150;
    }

    if(bnoPinky.hasNewQuaternion){
      // Serial.println("pinky");
      Quaternion sensorQuaternion;
      float radAccuracy;
      uint8_t accuracy;
      bnoPinky.getQuat(sensorQuaternion.x, sensorQuaternion.y, sensorQuaternion.z, sensorQuaternion.w, radAccuracy, accuracy);                    // get the pinky IMU quaternion
      // Serial.print(radAccuracy);
      // Serial.print(" ");
      // Serial.println(accuracy);

      fingerPinky.computeAxesValues(relativeQuaternion, sensorQuaternion);  // compute curl and splay axis from reference quaternion and finger quaternion

      controller_data.pinky_curl = fingerPinky.curlAxis;
      controller_data.pinky_splay = fingerPinky.splayAxis;
    }

    // printControllerData();
    // printSerialData();

    if(!runningCalibration){
      if(serial_data.rxed_data.index && serial_data.rxed_data.middle && serial_data.rxed_data.ring && serial_data.rxed_data.pinky){
        if(!allFingersWereTouchingBefore){
          millisWhenAllFingersAreTogether = millis();
          allFingersWereTouchingBefore = true;
          preparingCalibration = true;
          // Serial.println("Preparing calibration");
        }
      } else {
        allFingersWereTouchingBefore = false;
        preparingCalibration = false;
      }

      if(preparingCalibration && millis() - millisWhenAllFingersAreTogether > 5000){
        // Serial.println("run calibration");
        runningCalibration = true;
        preparingCalibration = false;
      }
    } else {
      runSplayCalibration();

      controller_data.index_curl = 0;
      controller_data.index_splay = 512;
      controller_data.middle_curl = 0;
      controller_data.middle_splay = 512;
      controller_data.ring_curl = 0;
      controller_data.ring_splay = 512; 
      controller_data.pinky_curl = 0;
      controller_data.pinky_splay = 512;
    }

    // controller_data.index_curl = 0;
    // controller_data.middle_curl = 0;
    // controller_data.ring_curl = 0;
    // controller_data.pinky_curl = 0;
    // static int i = 0;
    // if(i == 0){
    //   controller_data.index_splay = 512;
    //   controller_data.middle_splay = 512;
    //   controller_data.ring_splay = 0; 
    //   controller_data.pinky_splay = 1023;
    //   i++;
    // } else if(i == 1){
    //   controller_data.index_splay = 512;
    //   controller_data.middle_splay = 512;
    //   controller_data.ring_splay = 512; 
    //   controller_data.pinky_splay = 1023;
    //   i++;
    // } else if(i == 2){
    //   controller_data.index_splay = 512;
    //   controller_data.middle_splay = 512;
    //   controller_data.ring_splay = 1023; 
    //   controller_data.pinky_splay = 1023;
    //   i = 0;
    // }

    send_data_to_the_tracker();

    // Serial.println(debugTransitions);
    // Serial.println(a_btn);
    // Serial.println(serial_data.rxed_data.ring);
    // Serial.println(" ");
    // if(disableInputs) Serial.println("Inputs disabled");


    // if(controller_data.thumb_curl == 700) thumbCurlUp = false;
    // else if(controller_data.thumb_curl == 520) thumbCurlUp = true;
    // if(controller_data.index_curl == 700) indexCurlUp = false;
    // else if(controller_data.index_curl == 520) indexCurlUp = true;
    // if(controller_data.middle_curl == 700) middleCurlUp = false;
    // else if(controller_data.middle_curl == 520) middleCurlUp = true;
    // if(controller_data.ring_curl == 700) ringCurlUp = false;
    // else if(controller_data.ring_curl == 520) ringCurlUp = true;
    // if(controller_data.pinky_curl == 700) pinkyCurlUp = false;
    // else if(controller_data.pinky_curl == 520) pinkyCurlUp = true;

    // if(thumbCurlUp) controller_data.thumb_curl++; 
    // else controller_data.thumb_curl--;
    // if(indexCurlUp) controller_data.index_curl++; 
    // else controller_data.index_curl--;
    // if(middleCurlUp) controller_data.middle_curl++; 
    // else controller_data.middle_curl--;
    // if(ringCurlUp) controller_data.ring_curl++; 
    // else controller_data.ring_curl--;
    // if(pinkyCurlUp) controller_data.pinky_curl++; 
    // else controller_data.pinky_curl--;

    // if(controller_data.thumb_splay == 700) thumbSplayUp = false;
    // else if(controller_data.thumb_splay == 520) thumbSplayUp = true;
    // if(controller_data.index_splay == 700) indexSplayUp = false;
    // else if(controller_data.index_splay == 520) indexSplayUp = true;
    // if(controller_data.middle_splay == 700) middleSplayUp = false;
    // else if(controller_data.middle_splay == 520) middleSplayUp = true;
    // if(controller_data.ring_splay == 700) ringSplayUp = false;
    // else if(controller_data.ring_splay == 520) ringSplayUp = true;
    // if(controller_data.pinky_splay == 700) pinkySplayUp = false;
    // else if(controller_data.pinky_splay == 520) pinkySplayUp = true;

    // if(thumbSplayUp) controller_data.thumb_splay++; 
    // else controller_data.thumb_splay--;
    // if(indexSplayUp) controller_data.index_splay++; 
    // else controller_data.index_splay--;
    // if(middleSplayUp) controller_data.middle_splay++; 
    // else controller_data.middle_splay--;
    // if(ringSplayUp) controller_data.ring_splay++; 
    // else controller_data.ring_splay--;
    // if(pinkySplayUp) controller_data.pinky_splay++; 
    // else controller_data.pinky_splay--;

    // printControllerData();

    // if(controller_data.a) {
    //   abtnCounter++;
    //   Serial.print(abtnCounter);
    //   Serial.print(" ");
    //   Serial.println("a");
    // } if(controller_data.b) {
    //   bbtnCounter++;
    //   Serial.print(bbtnCounter);
    //   Serial.print(" ");
    //   Serial.println("b");
    // } if(controller_data.system) {
    //   systembtnCounter++;
    //   Serial.print(systembtnCounter);
    //   Serial.print(" ");
    //   Serial.println("system");
    // } if(controller_data.triggerbtn) {
    //   triggerbtnCounter++;
    //   Serial.print(triggerbtnCounter);
    //   Serial.print(" ");
    //   Serial.println("trigger");
    // } if(controller_data.thumbstick_click) {
    //   thumbstickbtnCounter++;
    //   Serial.print(thumbstickbtnCounter);
    //   Serial.print(" ");
    //   Serial.println("thumbstick");
    // }
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

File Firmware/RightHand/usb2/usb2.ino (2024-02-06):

#include "BNO085.h"
#include "Quaternion.h"
#include <cmath>

#define THUMB_CONTACT_PIN 22
#define INDEX_CONTACT_PIN 23
#define MIDDLE_CONTACT_PIN 24
#define RING_CONTACT_PIN 25
#define PINKY_CONTACT_PIN 26

BNO085 bnoRef;
BNO085 bnoThumb;

Quaternion handRotationInNewGlove;
Quaternion hackyHandRotation;
Quaternion thumbRotationInNewGlove;
Quaternion hackyThumbRotation;

Quaternion handQuaternionThatWorks;
Quaternion handQuaternionThatWorksForMainMCU; // this is here to speed things up, the four fingers should also follow handQuaternionThatWorks, but they were prepared for this first and I want to be fast now
Quaternion handQuaternion;
Quaternion relativeQuaternion;
Quaternion relativeQuaternionForMainMCU; // this is here to speed things up, the four fingers should also follow handQuaternionThatWorks, but they were prepared for this first and I want to be fast now
Quaternion relativeJoystickQuaternion;

Quaternion thumbQuaternion;
Quaternion thumbNeutralToHandQuaternion;
Quaternion thumbNeutralToHandQuaternionForCurl;
Quaternion thumbNeutralJoystickToHandQuaternion;

Quaternion indexQuaternion;
Quaternion middleQuaternion;
Quaternion ringQuaternion;
Quaternion pinkyQuaternion;

// float getCurl(Quaternion q){
//   return atan2(2 * (q.x * q.w - q.y * q.z), 1 - 2 * (q.x * q.x + q.y * q.y));
// }

// float getSplay(Quaternion q){
//   return atan2(2 * (q.x * q.y + q.z * q.w), 1 - 2 * (q.y * q.y + q.z * q.z));
// }

// float getRoll(Quaternion q){
//   return atan2(2 * (q.y * q.z + q.w * q.x), 1 - 2 * (q.x * q.x + q.y * q.y));
// }

// float getRoll(Quaternion q){
//   return asin(2 * (q.x * q.y - q.w * q.z));
// }

// float getYaw(Quaternion q){
//   return atan2(2 * (q.w * q.y + q.x * q.z), (q.w * q.w + q.x * q.x - q.y * q.y - q.z * q.z));
// }

// float getPitch(Quaternion q){
//   return atan2(2 * (q.w * q.x + q.y * q.z), (q.w * q.w - q.x * q.x + q.y * q.y - q.z * q.z));
// }

Quaternion quaternionFromAngle(float angle, int axis){
  // angle is in radians, x axis is 0, y axis is 1, z axis is 2
  if (axis == 0){
    Quaternion q;
    q.w = cos(angle/2);
    q.x = sin(angle/2);
    q.y = 0;
    q.z = 0;
    return q;
  }
  if (axis == 1){
    Quaternion q;
    q.w = cos(angle/2);
    q.x = 0;
    q.y = sin(angle/2);
    q.z = 0;
    return q;
  }
  if (axis == 2){
    Quaternion q;
    q.w = cos(angle/2);
    q.x = 0;
    q.y = 0;
    q.z = sin(angle/2);
    return q;
  }
}

// this will be sent by serial to the main MCU - 14 bytes are enough for 112 bits, this struct has 108
typedef struct __attribute__( ( packed, aligned( 1 ) ) )
{
  uint8_t       pinky           : 1;  //0
  uint8_t       ring            : 1;  //1
  uint8_t       middle          : 1;  //2
  uint8_t       index           : 1;  //3
  uint16_t      thumbstick_x    : 10; //4
  uint16_t      thumbstick_y    : 10; //14
  uint16_t      thumbCurl       : 10; //24
  uint16_t      thumbSplay      : 10; //34
  int16_t       refQuaternion_w : 16; //44
  int16_t       refQuaternion_x : 16; //60
  int16_t       refQuaternion_y : 16; //76
  int16_t       refQuaternion_z : 16; //92
} serial_data_t;
serial_data_t serial_data;

long microsOfTheLastMessageSent = 0;

// the setup function runs once when you press reset or power the board
void setup() {

  Serial.begin(115200);
  // while(!Serial) // can't use this here, otherwise it only works with usb connected!

  delay(1000);
  Serial.println("ImmersiveGloves starting...");
  delay(3000); // wait 3 seconds, USB1 only waits 1 second, so that we are sure USB2 has UART aligned for now - probably will make this better later


  // Initialize I2C
  _i2c_init(i2c0, 400000);             // Init I2C0 peripheral at 400kHz
  gpio_set_function(0, GPIO_FUNC_I2C); // set pin 4 as an I2C pin (SDA in this case)
  gpio_set_function(1, GPIO_FUNC_I2C); // set pin 5 as an I2C pin (SCL in this case)
  gpio_pull_up(0);                     // use internal pull up on pin 4
  gpio_pull_up(1);                     // use internal pull up on pin 5
  Serial.println("I2C0 configured");

  // _i2c_init(i2c1, 400000);             // Init I2C1 peripheral at 400kHz
  // gpio_set_function(14, GPIO_FUNC_I2C); // set pin 2 as an I2C pin (SDA in this case)
  // gpio_set_function(15, GPIO_FUNC_I2C); // set pin 3 as an I2C pin (SCL in this case)
  // gpio_pull_up(14);                     // use internal pull up on pin 2
  // gpio_pull_up(15);                     // use internal pull up on pin 3
  // Serial.println("I2C1 configured");
  
  // Set up our UART with the required speed.
  uart_init(uart1, 115200);
  // Set the TX and RX pins by using the function select on the GPIO
  // Set datasheet for more information on function select
  gpio_set_function(4, GPIO_FUNC_UART);
  gpio_set_function(5, GPIO_FUNC_UART);

  // Reference functions below:
  // uart_putc_raw(uart1, 'A');           // Send out a character without any conversions
  // uart_putc(uart1, 'B');               // Send out a character but do CR/LF conversions
  // uart_puts(uart1, " Hello, UART!\n"); // Send out a string, with CR/LF conversions

  delay(1000);                         // Give the IMUs time to boot up

  bnoRef.begin(i2c0, 0x4B);
  bnoThumb.begin(i2c0, 0x4A);
  // bnoIndex.begin(i2c0, 0x4B);
  // bnoMiddle.begin(i2c1, 0x4A);
  // bnoRing.begin(i2c0, 0x4B);
  // bnoPinky.begin(i2c1, 0x4A);


  handQuaternionThatWorks.w = 1;
  handQuaternionThatWorks.x = 0;
  handQuaternionThatWorks.y = 0;
  handQuaternionThatWorks.z = 0;

  handQuaternionThatWorksForMainMCU.w = sqrt(2)/2;
  handQuaternionThatWorksForMainMCU.x = 0;
  handQuaternionThatWorksForMainMCU.y = 0;
  handQuaternionThatWorksForMainMCU.z = -sqrt(2)/2;

  // for the thumb movement, I needed to get a first neutral position from which to take rotations
  // the relative rotation to the reference IMU is represented by the quaternion below, taken experimentally

  thumbNeutralToHandQuaternion.w = 0.57;
  thumbNeutralToHandQuaternion.x = 0.73;
  thumbNeutralToHandQuaternion.y = -0.37;
  thumbNeutralToHandQuaternion.z = 0.00;

  thumbNeutralToHandQuaternionForCurl.w = 0.62;
  thumbNeutralToHandQuaternionForCurl.x = 0.74;
  thumbNeutralToHandQuaternionForCurl.y = 0.01;
  thumbNeutralToHandQuaternionForCurl.z = -0.26;

  // for the joystick emulation, I need a neutral rotation from which to take roll and pitch and map it into joystick values
  // the relative rotation to the reference IMU is represented by the quaternion below, taken experimentally
  thumbNeutralJoystickToHandQuaternion.w = 0.64;
  thumbNeutralJoystickToHandQuaternion.x = 0.72;
  thumbNeutralJoystickToHandQuaternion.y = -0.13;
  thumbNeutralJoystickToHandQuaternion.z = -0.22;

  // _gpio_init(22);
  // gpio_set_dir(22,false); // set GPIO22 as input
  pinMode(THUMB_CONTACT_PIN,OUTPUT);
  digitalWrite(THUMB_CONTACT_PIN, false);
  pinMode(INDEX_CONTACT_PIN,INPUT_PULLUP);
  pinMode(MIDDLE_CONTACT_PIN,INPUT_PULLUP);
  pinMode(RING_CONTACT_PIN,INPUT_PULLUP);
  pinMode(PINKY_CONTACT_PIN,INPUT_PULLUP);
}
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

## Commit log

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2023-10-10 Saving work before fix
    [code.py]
2023-10-14 Communication is perfect now
    PC receives all data, but there are issues with the driver, it looks
    like it does not exist :D
    [code.py]
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2023-10-15 Adjusting coordinate frame
    This change in the "head" attribute of the json allows steam vr to
    orient the render model correctly
2023-10-20 Reorganizing files, demo of many IMUs ok
    Finger angle is not in fact ok, I made a mistake somewhere in my
    quaternion math that was not apparent when prototyping in the
    breadboard. Must check this next.
    [IMUBoard.kicad_pcb, IMUBoard.kicad_sch, IMUBoard1QwiicConnector.kicad_pcb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]
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2023-10-22 Fingers now work in any hand orientation
    I don't know why the relative quaternions between the fingers and
    reference IMUs was changing if I changed my hand orientation. That
    should not happen. But since it was working fine in a specific hand
    orientation, I got the idea of taking the relative quaternions of
    everything, reference and fingers, to that orientation and moving
    everything to that rotation, basically undoing the rotation in math.
    Then, doing the relative stuff on that new reference frame worked.
    Also fixed a little bug with the pinky finger.
    Now I have 4 finger curls working, yeah!!
    [code.py]
2023-10-24 Renaming driver resources for upcoming driver
    - Now all tmi_hand_controller metadata has become
    immersive_gloves_controller in preparation for the driver I'm going to
    develop next.
    - Also, the .json used to configure the Tundra Tracker
    firmware has been updated to change the driver name so I can develop the
    driver in a proper, dedicated folder.
    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
    [tmi_hand_controller.obj]
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2023-10-26 Driver customized, two jsons for right and left
    Now I know how to customize the data sent from each controller, left and
    right, to steam vr. Not only that, I can set its values. They match with
    the controller profiles.
    Now on steam vr I have what looks like 2 virtual controllers that are
    always ON and 2 controllers that correspond to my real trackers and that
    can be ON or OFF depending on their real state. I should only have 2,
    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
    [tmi_hand_controller.obj]
2023-10-28 Fixing input profile, bad offsets
    Some prototyping on the driver too and firmware code debugging line
    added, but the main thing was the input profile that did not show input
    after the simplification efforts
    [code.py]
2023-10-28 Updated device json files for hand sides
    This makes the gloves identify themselves as right and left as soon as
    they are detected by steamvr. The left hand json was also updated to
    mirror the rendermodel and match the expected hand orientation. Position
    is a bit off but I will keep that for later.
    Also removing the drivers folder that has been deprecated.
    [tmi_hand_controller.obj]
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2023-11-08 Finished integrating placeholder hooks in driver
    Will need to customize for my needs now, just copied some parts from the
    etee vr repo
    [immersive_gloves_controller.obj, tmi_hand_controller.obj]
2023-11-10 Successfully got data from tracker using hooks
    I also know from what hand the finger data is coming from. Now I only
    need to implement the named pipes. The way I was doing in the hello
    opengl project sample from openvr does not work very well here due to
    some dependency issues I am in the middle of solving. This will be the
    next step to tackle.
2023-11-11 Pipes now working with real data
    Ring finger and pinky finger are switched and I don't know if it is my
    fault or there is a bug in open gloves
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2023-11-12 Now getting proper input names for finger data
    Ring and pinky finger were switched before. After changing how each
    finger is identified to use its input name, the problem was fixed.
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2023-11-20 Updating smallest IMU board
    Will probably make it even smaller by hardwiring PS0, PS1 and SDO pins.
    And maybe even the connector can go to give room for a cable bundle of 4
    wires soldered to the board directly.
    [IMUBoard1QwiicConnector.kicad_pcb, IMUBoard1QwiicConnector.kicad_sch]
2023-11-21 Making the IMU board on the finger tip smaller
    Just saving work to continue at lunch, will use 4 layer pcb for the
    board to be as small as possible
    [IMUBoard1QwiicConnector.kicad_pcb, IMUBoard1QwiicConnector.kicad_sch, IMUBoard1QwiicConnector.step]
2023-11-21 Smaller IMU board achieved, needs centering
    So it is possible to get a JST and BNO085 in a board around 9x8mm. This
    looks good enough for the finger tip
    [IMUBoard1QwiicConnector.kicad_pcb]
2023-11-22 9x8mm format achieved with everything centered
    This allows some margin on the sides for a 3D printed insert
    to stabilize the board on the glove finger tips
    [IMUBoard1QwiicConnector-B_Cu.gbr, IMUBoard1QwiicConnector-B_Mask.gbr, IMUBoard1QwiicConnector-B_Paste.gbr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]
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2023-11-22 Adding variant for BNO 0x4A and 0x4B addresses
    Also cleaned up the folder structure and changed schematic for the
    custom Tundra expansion board
    [BNO085_0x4A_Board.kicad_pcb, BNO085_0x4A_Board.kicad_sch, BNO085_0x4B_Board.kicad_pcb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]
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2023-11-23 Connectors and ICs placed on rough locations
    Also took care of board layout curves
    [tundraIOExpansion.kicad_pcb]
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2023-11-24 Most components placed on tundra interface pcb
    Decoupling caps next and then maybe adding some more connectors where
    possible for future functionality expansion
    [tundraIOExpansion.kicad_pcb, tundraIOExpansion.kicad_sch]
2023-11-24 Fixing board outline
    [tundraIOExpansion.kicad_pcb]
2023-11-25 Component placement complete
    Will still experiment with inputs first so I know what kind of
    connectors will be needed to get whatever buttons or joysticks may be
    inplemented. Only after that's done will the routing of the tracks
    start.
    [tundraIOExpansion.kicad_pcb, tundraIOExpansion.kicad_sch]
2023-11-25 Adding auxiliary connectors for mixed inputs
    I am still not sure what input types I will have, but I am preparing the
    board to be flexible, exposing 8 GPIOs, 4 of which are analog to digital
    converters.
    I have also started to design the hardware interface with a second board
    that can be placed below the main one, to add two rp2040 to the project
    if needed.
    [tundraIOExpansion.kicad_pcb, tundraIOExpansion.kicad_sch]
2023-11-27 Fixing SPI packet length limitation on rp2040
    SPI packet length needed to be fixed from 13 to 15 bytes to fit the new
    joystick data being sent through the Tundra. That's why it wasn't
    working before.
    [code.py]
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2023-12-02 Updating IMU boards for different wire connections
    Now all components are placed on one layer, making assembly easier. The
    JST connector was dropped for smalled IMU housing, instead the wires now
    solder directly to the board and exit from the sides of the board.
    [BNO085_0x4A_Board-B_Cu.gbr, BNO085_0x4A_Board-B_Mask.gbr, BNO085_0x4A_Board-B_Paste.gbr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]
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2023-12-03 Finished tundra expansion board
    Had to add a pull up resistor on QSPI_SS on each RP2040 to enable
    BOOT_SEL feature when booting with external jumper/button pressed on
    USB, to support booting as external flash storage.
    [tundraIOExpansion-B_Cu.gbr, tundraIOExpansion-B_Mask.gbr, tundraIOExpansion-B_Paste.gbr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]
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2024-01-01 Adding thumb and joystick, fixing pins
    Preparing final firmware for the MCU that takes care of reference and
    thumb IMUs.
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2024-01-02 Removing index finger from usb2
    Also changing the quaternion that is sent from usb2 to usb1, now sending
    relative as is correct, instead of sending the handQuaternion that has a
    known value after being rotated.
    [usb2.ino]
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2024-01-02 Comms between MCU's somewhat working
    Must fix an alignment bug still, but the core is more or less done
    [usb1.ino, usb2.ino]
2024-01-02 Initiator AA added, data aligned now
    thumb curl and splay comes bodged, don't know if it's the parsing or if
    it is sent like that already.
    [usb1.ino, usb2.ino]
2024-01-03 Finally fixed data share between MCUs
    [usb1.ino, usb2.ino]
2024-01-13 Saving everything before returning to older commit
    I'm lazy, tired, and I may forget to stash apply later, sorry for the
    mess, me from the future
    [StencilBottom.stl, StencilTop.stl, StensilJig.FCStd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]
2024-01-28 Fixing mistakes on the main board
    Flash chip was not the recommended by raspberry pi foundation - fixed.
    SCL and SDA pins on the thumb JST connectors were switched - fixed.
    MOSI and MISO pins on the RP2040 were switched - fixed.
    [tundraIOExpansion.kicad_pcb, tundraIOExpansion.kicad_sch]
2024-01-28 Fixing USB connectors on main board
    Forgot to invert the USB connectors, these were wrong too on the first
    batch.
    [tundraIOExpansion.kicad_pcb, tundraIOExpansion.kicad_sch]
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2024-01-30 Fixing thumb related stuff
    This probably finishes firmware, but should confirm
    [Quaternion.cpp, usb2.ino]
2024-01-30 The firmware is for RightHand, not LeftHand, fixed
    [BNO085.cpp, BNO085.h, Quaternion.cpp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]
2024-01-31 Adding Tundra comms, tweaking splay
    I can see fingers moving on steam vr again with higher update rate.
    Latency looks to still be an issue, but I'll have to look into it later.
    Could be coming from many places or maybe I just need to put VR on and
    it's just not there (currently checking VR view).
    [BNO085.cpp, mapped_input_types.h, tundra_mapped_input.cpp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]
2024-02-02 Will send messages from usb2 to usb1 periodically
    Until now, messages were sent as soon as the cycle reached the send
    part. This is not efficient since it may be sending the same message
    many times if there is no data available on the IMUs, and this way I can
    make usb1 know when a message starts and ends by looking at inactive
    time on the uart. I'll also implement a CRC on the message, I've seen
    some incorrect data being parsed and the CRC will just drop those
    messages. With these two implementations it should be fixed.
    [usb2.ino]
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2024-02-05 Starting implementation of spi slave via PIO
    I think there are some issues with the hardware SPI and I will try to
    implement this just like what I've done before with python
    [usb1.ino]
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2024-02-06 Fixing anoying bug small curl angles.
    Also dumping the whole repo to the most updated version.
    Will clean later.
    [Quaternion.cpp, code.py]
2024-02-09 Fixed calibration, organizing firmware code
    Now only getting mid values after calibration and setting min and max by
    subtracting and adding 30 degrees to the mid values of each finger. This
    makes tracking much more accurate.
    [usb1.ino]
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2024-02-22 Adding mags to lsm/bmi chips
    Going to use one or the other, depending whether lsm or bmi is used
    [multi_imu.kicad_pcb, multi_imu.kicad_sch]
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2024-02-26 BMI160+mag board finished, fixed CS on ICM-20948
    [6-TSOP.STEP, BMI160-and-QMC5883L_Second_Bone.kicad_pcb, BSS138BKS,115.stp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]
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
